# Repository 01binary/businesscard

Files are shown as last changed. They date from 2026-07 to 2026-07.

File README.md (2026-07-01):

# Interactive Business Card

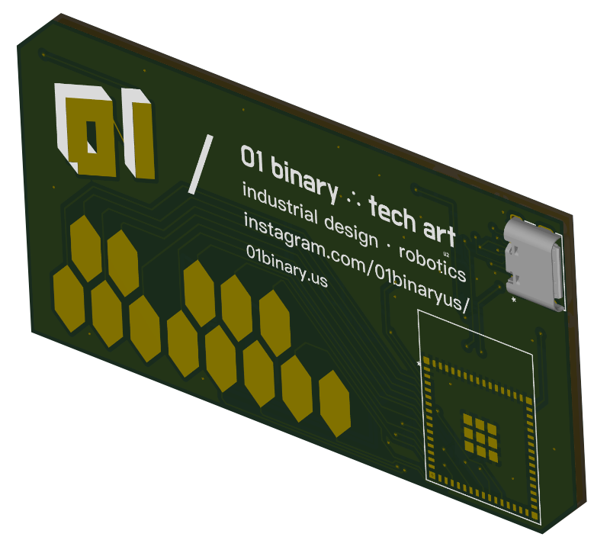
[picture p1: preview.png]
preview


A two-sided PCB business card designed in `KiCad 9`, built around an `ESP32-S2-MINI-2` module, powered by `USB-C` or a `CR2032` coin cell.

+ Capacitive-Touch Piano Keys (`C4`–`C5`, one octave)
+ Piezo Speaker (Monophonic Tone Playback)
+ Capacitive Logo Touch Pad (Wake / Power Control)
+ USB-C or `CR2032` Power, Auto-Switched
+ Deep Sleep for Low Power Consumption

## Modules

The following module is placed onto the board:

|Module|Function|
|-|-|
|`ESP32-S2-MINI-2-N4`|MCU module with native USB, capacitive-touch inputs, and deep sleep|

## Power

Power comes from either a `USB-C` connector (through a `3.3V` LDO regulator) or a `CR2032` coin cell battery.

A `TPS2121` power multiplexer (`U_PWR`) automatically prioritizes `USB` power when plugged in, and switches back to coin cell power when unplugged, with no interruption to the `3.3V` rail.

| Stage | Component | Function |
|-|-|-|
| `USB` → `3.3V` | `AP2112K-3.3` (`U2`) | LDO regulator, converts `VBUS` (`5V`) down to `3.3V` |
| `USB` / Battery Switch | `TPS2121` (`U_PWR`) | Selects `USB 3.3V` or `CR2032 3V`, prioritizing `USB` |
| Coin Cell | Keystone `3034` (`BT1`) | Holder for `20mm CR2032` battery |

Decoupling/bulk capacitors on the `3.3V` rail:

|Capacitor|Value|Purpose|
|-|-|-|
|`C1`|`100µF`|Bulk capacitor, stabilizes rail against low-frequency dips (battery power draw)|
|`C2`|`10µF`|LDO output filter|
|`C3`|`0.1µF`|Local high-frequency bypass near the MCU|

### USB-C Configuration

The `USB-C` receptacle (`J1`) is configured for `UFP` (Upstream Facing Port) mode, meaning the card acts as a `USB` device, not a host.

+ `CC1` and `CC2` are each pulled to `GND` through `5.1kΩ` resistors (`R1`, `R2`), advertising the device role per the `USB Type-C` spec.
+ Only one of `CC1`/`CC2` is active depending on cable orientation, but both are populated so the connector works either way.
+ When plugged in, the host detects the pull-downs and supplies `5V` on `VBUS`.
+ No `USB-PD` negotiation is needed since the board only draws default `5V` at low current.

## Touch Interface

The front of the card has 13 capacitive touch pads forming one octave of piano-style keys (`C4`–`C5`), plus a two-piece logo pad that is electrically bridged into a single touch input.

+ Touching a piano key plays its corresponding tone through the piezo speaker.
+ Touching the logo pad wakes the device from deep sleep and acts as the soft power button.
+ After a period of inactivity, the firmware drops to a reduced CPU frequency and then enters deep sleep; touching the logo is the wake source.
+ All touch pads and I/O are additionally brought out as test points for flexibility in layout and debugging.

## Audio

When a key is touched, the firmware plays a monophonic tone through a piezo transducer (`LS1`), driven differentially from two `GPIO` pins through `100Ω` series resistors (`R3`, `R4`).

## Buttons

|Button|Function|
|-|-|
|`SW1`|`RESET` — pulls `EN` low to reset the MCU|
|`SW2`|`BOOT` — pulls `GPIO0` low to enter flashing mode|

## Pins

|Pin|Function|
|-|-|
|`GPIO19`|USB `D-` (`J1`)|
|`GPIO20`|USB `D+` (`J1`)|
|`GPIO0`|`BOOT` Button (`SW2`)|
|`EN`|`RESET` Button (`SW1`)|
|`3V3`|Power input from `U_PWR` (`TPS2121`) `OUT`|
|`GPIO26`|Piezo Driver `A` → `R3` → `LS1 +`|
|`GPIO17`|Piezo Driver `B` → `R4` → `LS1 -`|
|`GPIO1`|Touch Key `C` (`TP1`)|
|`GPIO2`|Touch Key `C#` (`TP2`)|
|`GPIO3`|Touch Key `D` (`TP3`)|
|`GPIO4`|Touch Key `D#` (`TP4`)|
|`GPIO5`|Touch Key `E` (`TP5`)|
|`GPIO6`|Touch Key `F` (`TP6`)|
|`GPIO7`|Touch Key `F#` (`TP7`)|
|`GPIO8`|Touch Key `G` (`TP8`)|
|`GPIO9`|Touch Key `G#` (`TP9`)|
|`GPIO10`|Touch Key `A` (`TP10`)|
|`GPIO11`|Touch Key `A#` (`TP11`)|
|`GPIO12`|Touch Key `B` (`TP12`)|
|`GPIO13`|Touch Key `C` (octave up) (`TP13`)|
|`GPIO14`|Touch Logo Pad, wake source (`TP14`, bridged)|

## Bill of Materials

|Component|Description|
|-|-|
|[ESP32-S2-MINI-2-N4](https://www.digikey.com/en/products/result?keywords=ESP32-S2-MINI-2-N4)|Main MCU with native USB and capacitive-touch capability|
|[AP2112K-3.3TRG1DICT-ND](https://www.digikey.com/en/products/result?keywords=AP2112K-3.3TRG1)|`3.3V` LDO regulator for USB power source|
|[TPS2121RUXR](https://www.digikey.com/en/products/result?keywords=TPS2121RUXR)|Power multiplexer, auto-switches between USB `3.3V` and `CR2032` battery|
|[Keystone 3034](https://www.digikey.com/en/products/result?keywords=3034)|Holder for `20mm CR2032` battery|
|[UJ20-C-H-G-MSMT-5-P16-TR](https://www.digikey.com/en/products/result?keywords=UJ20-C-H-G-MSMT-5-P16-TR)|USB-C receptacle for power and programming|
|[TLSMDT3C020GLFS](https://www.digikey.com/en/products/detail/c-k/TLSMDT3C020GLFS/14553425)|`SW1`/`SW2` Momentary pushbutton, RESET (`EN`) and BOOT (`GPIO0`)|
|[SMT-1141-T-5-R](https://www.digikey.com/en/products/detail/pui-audio-inc/SMT-1141-T-5-R/6192576)|Piezo transducer, audio output for tone playback|
|[RMCF0603FT5K10CTND](https://www.digikey.com/en/products/result?keywords=RMCF0603FT5K10)|`5.1kΩ` `0603` resistor, USB-C `CC` pull-downs (`R1`, `R2`)|
|[RMCF0603JT100RCTND](https://www.digikey.com/en/products/result?keywords=RMCF0603JT100R)|`100Ω` `0603` resistor, piezo driver series protection (`R3`, `R4`)|
|[CL32A107MPVNNNE](https://www.digikey.com/en/products/result?keywords=CL32A107MPVNNNE)|`100µF` capacitor, bulk power stabilization (`C1`)|
|[GRM21BR61C106KE15K](https://www.digikey.com/en/products/result?keywords=GRM21BR61C106KE15K)|`10µF` `0805` capacitor, LDO output filter (`C2`)|
|[CS0805KKX7R0BB104](https://www.digikey.com/en/products/result?keywords=CS0805KKX7R0BB104)|`0.1µF` `0603` capacitor, local bypass near MCU (`C3`)|

`TP1`–`TP13` are capacitive piano key electrodes (`C4`–`C5`); `TP14` is the two-piece logo pad bridged into a single wake-source input. Neither requires a physical component.

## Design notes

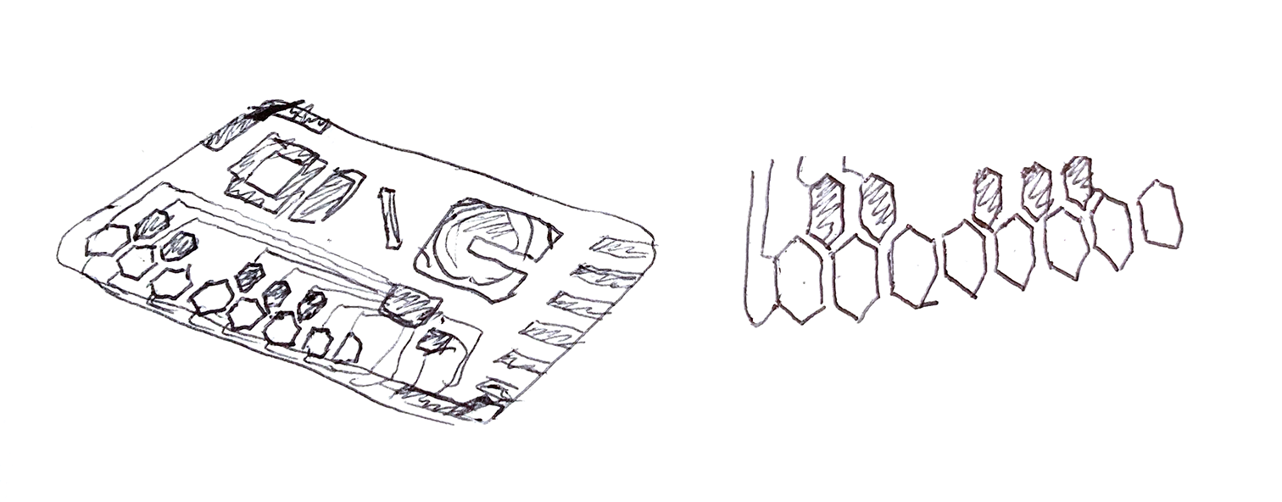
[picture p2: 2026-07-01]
design/concept.png

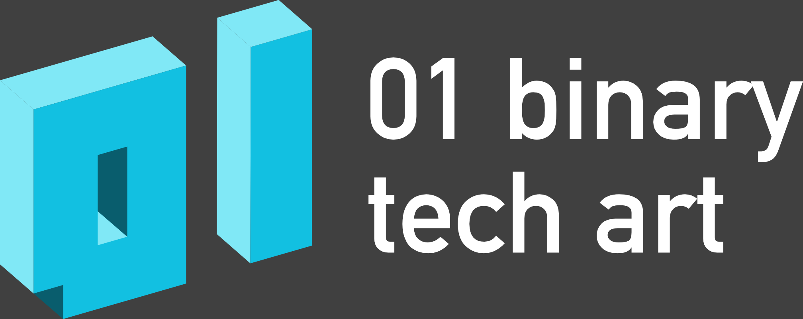
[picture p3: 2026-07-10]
design/01text.png

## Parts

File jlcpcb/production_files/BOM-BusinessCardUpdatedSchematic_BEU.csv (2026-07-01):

Comment | Designator | Footprint | LCSC | Quantity
0.1uF | C3,C6,C9 | CL10B104KA8NNNC | C1590 | 3
100 | R3,R4 | RESC1508X55N | C305084 | 2
100K | R5 | RC0805FR-07100KL | C96346 | 1
100uF | C1 | CAPC3225X280N | C23742 | 1
10K | R7,R8 | AF0805FR-0710KL | C192906 | 2
10uF | C2,C7 | CL10A106KP8NNNC | C19702 | 2
1uF | C4,C5 | GRM188R71A105KA61D | C97888 | 2
2171790001 | J1 | 2171790001_MOL | C45082768 | 1
3034 | BT1 | BAT_3034 | C5213768 | 1
5.1K | R1,R2 | RC0603FR-075K1L | C105580 | 2
AP2112K-3.3TRG1 | U2 | SOT95P285X140-5N | C51118 | 1
ESP32-S3-MINI-1-N8 | U3 | ESP32-S3-MINI-1-N8 | C2913206 | 1
TLSMDT3C020GLFS | SW2,SW3 | TS-1088-AR02016 | C720477 | 2
TPS2121RUXR | U_PWR1 | IC_TPS2121RUXR | C485916 | 1

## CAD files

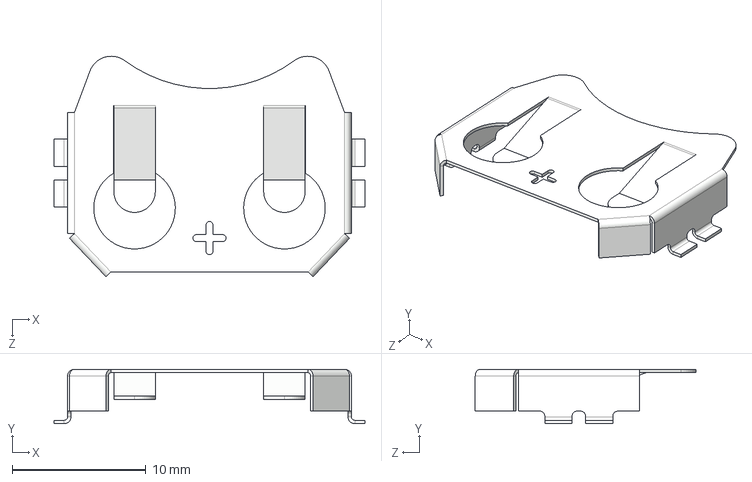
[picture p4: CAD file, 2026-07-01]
dependencies/6-3034-ND/3034.step
23.2 x 4.06 x 16.5 mm

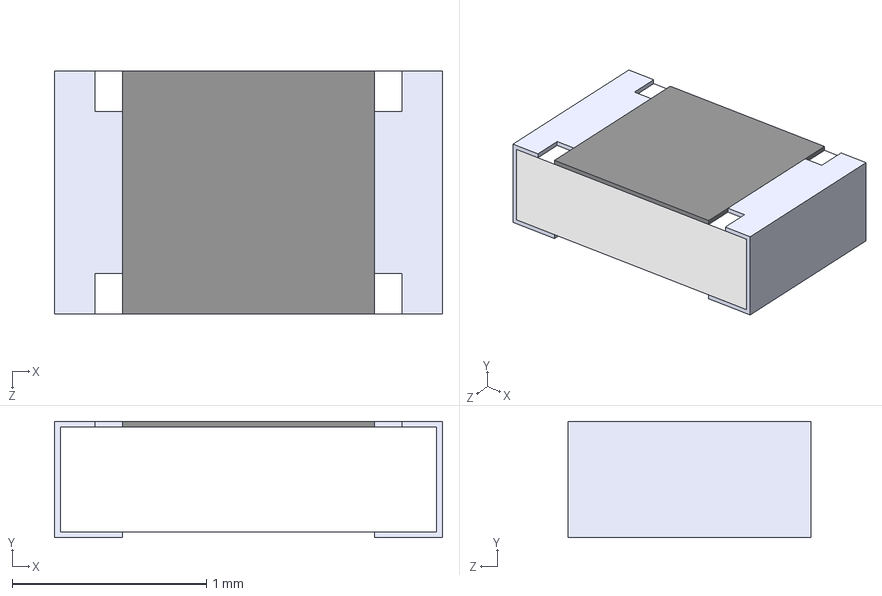
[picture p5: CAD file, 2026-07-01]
dependencies/AF0805FR-0710KL/AF0805FR-0710KL.step
2.00 x 0.6 x 1.25 mm

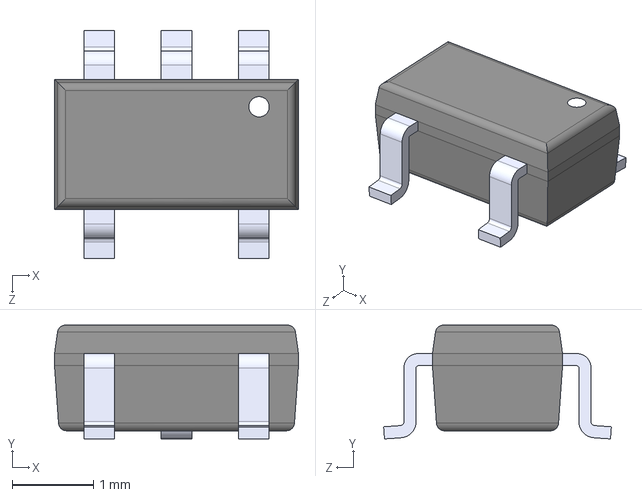
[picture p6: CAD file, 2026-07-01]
dependencies/AP2112K-3.3TRG1/AP2112K-3.3TRG1.step
3.00 x 1.40 x 2.80 mm

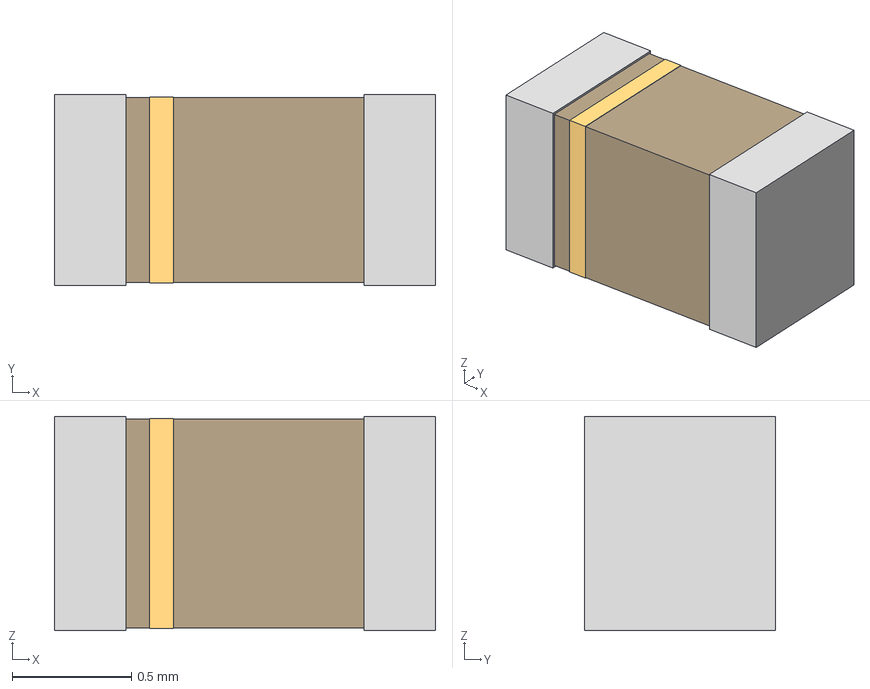
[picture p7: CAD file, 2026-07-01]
dependencies/CL10A106KP8NNNC/CL10A106KP8NNNC.step
1.60 x 0.8 x 0.9 mm

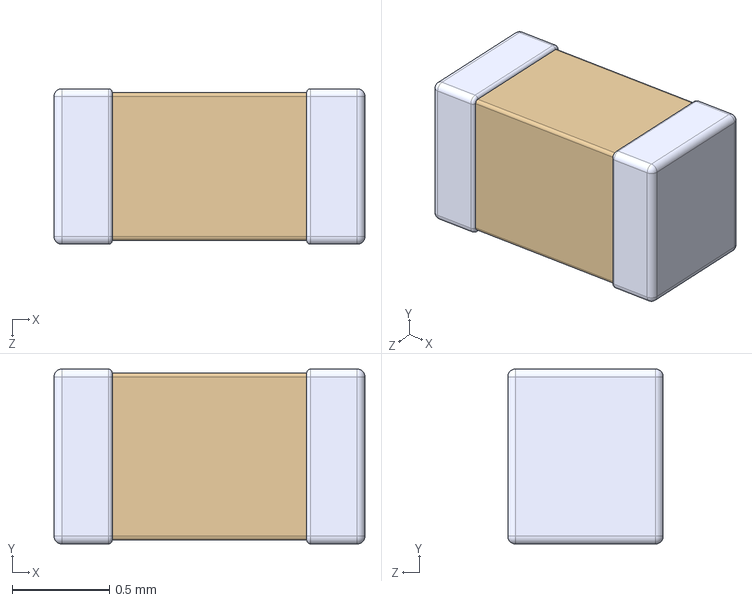
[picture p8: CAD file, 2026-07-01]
dependencies/CL10B104KA8NNNC/CL10B104KA8NNNC.step
1.60 x 0.9 x 0.8 mm

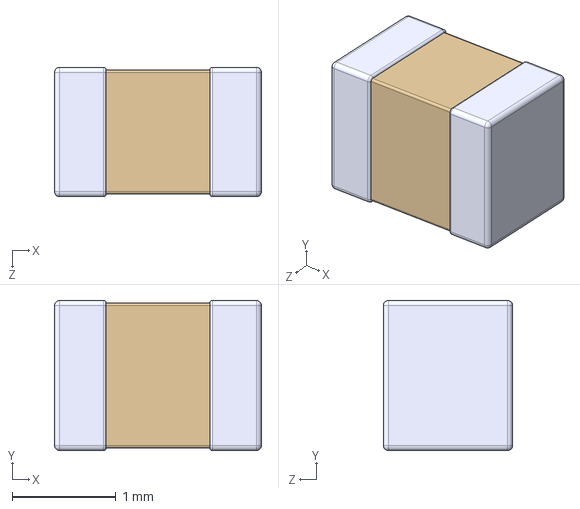
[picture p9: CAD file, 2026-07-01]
dependencies/CL21A106KAYNNNF/CL21A106KAYNNNF.step
2.00 x 1.45 x 1.25 mm

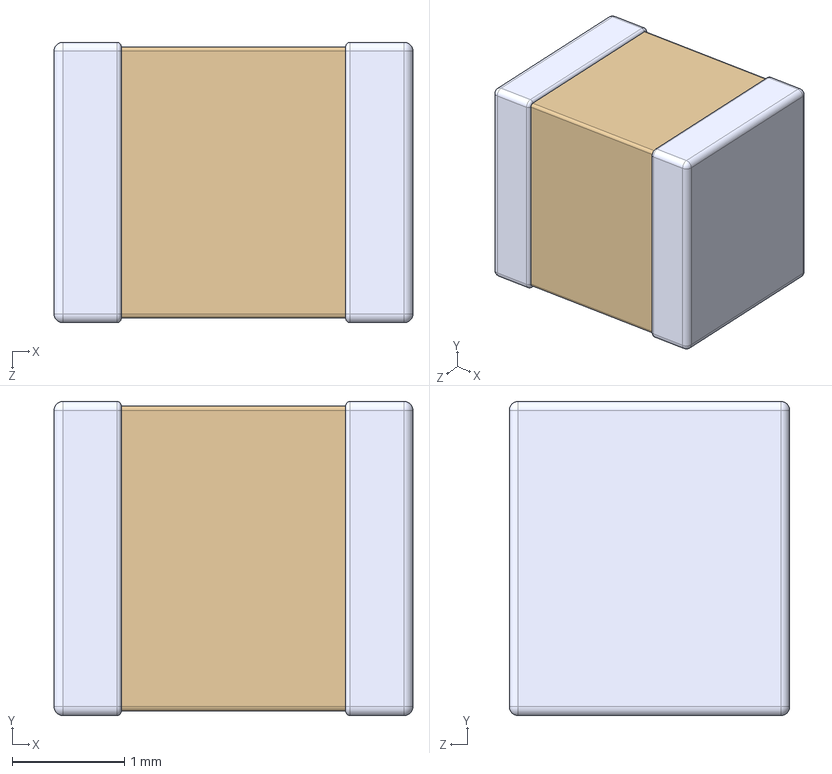
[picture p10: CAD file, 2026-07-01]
dependencies/CL32A107MPVNNNE/CL32A107MPVNNNE.step
3.20 x 2.80 x 2.50 mm

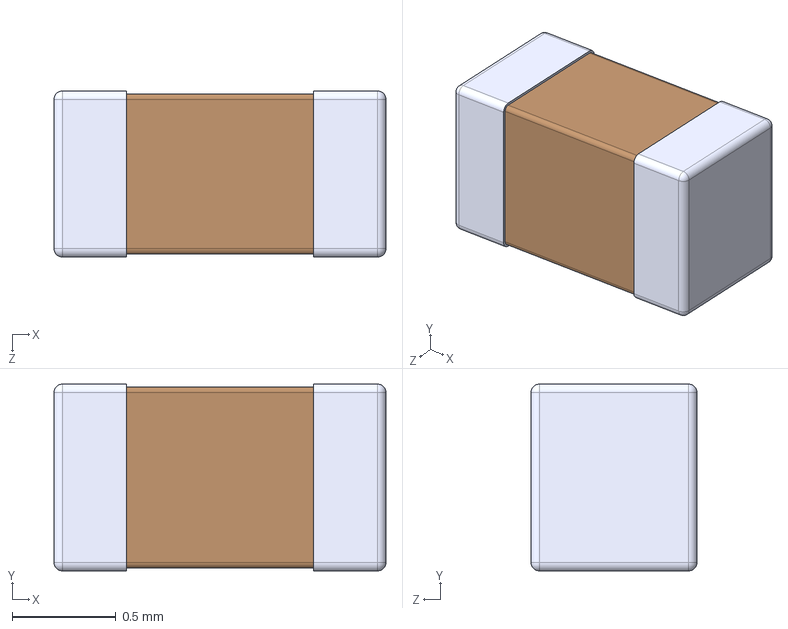
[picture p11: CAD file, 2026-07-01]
dependencies/GRM188R71A105KA61D/GRM188R71A105KA61D.step
1.60 x 0.9 x 0.8 mm

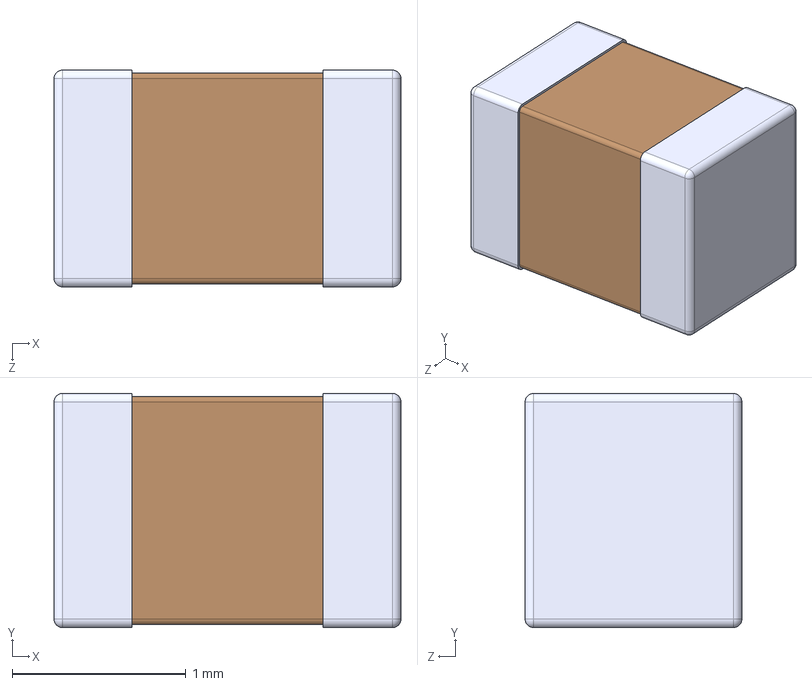
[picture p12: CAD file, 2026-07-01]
dependencies/GRM21BR61C106KE15K/GRM21BR61C106KE15K.step
2.00 x 1.35 x 1.25 mm

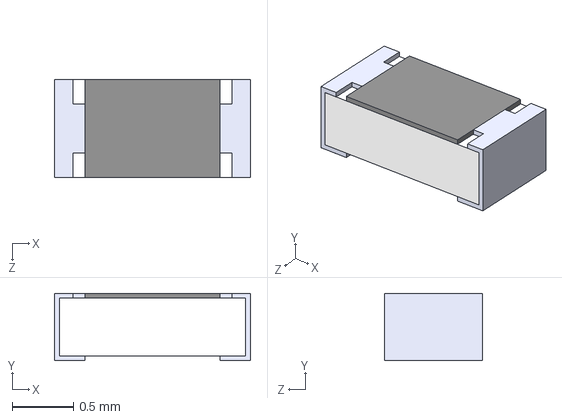
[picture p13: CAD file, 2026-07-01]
dependencies/RC0603FR-075K1L/RC0603FR-075K1L.step
1.60 x 0.55 x 0.8 mm

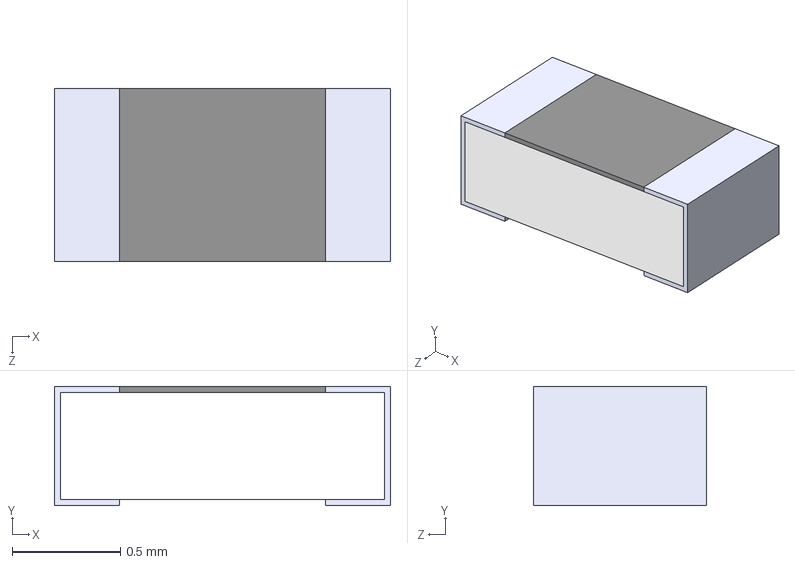
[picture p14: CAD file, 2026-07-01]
dependencies/RMCF0603FT5K10/RMCF0603FT5K10.step
1.55 x 0.55 x 0.8 mm

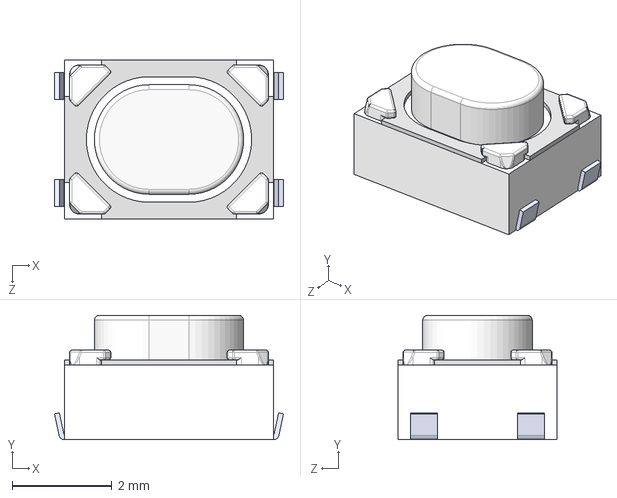
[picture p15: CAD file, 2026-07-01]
dependencies/SKRPABE010/SKRPABE010.step
4.60 x 2.50 x 3.20 mm

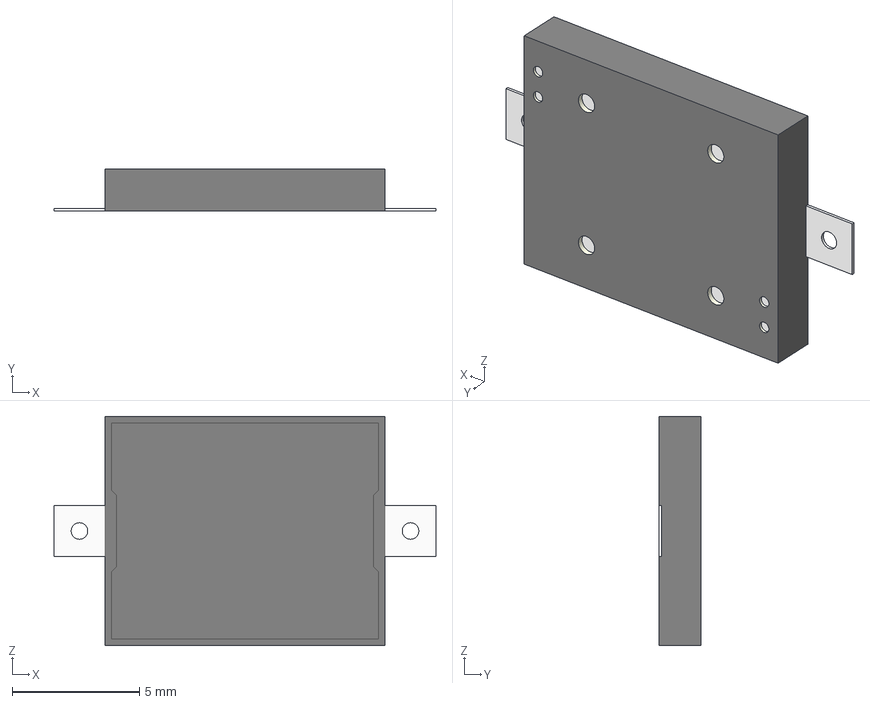
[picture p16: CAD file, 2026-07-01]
dependencies/SMT_1141_T_5_R/SMT-1141-T-5-R.step
15.0 x 1.65 x 9.00 mm

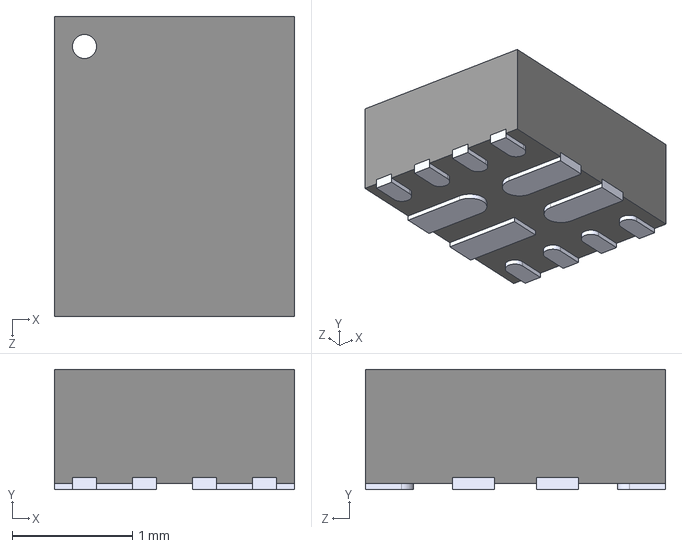
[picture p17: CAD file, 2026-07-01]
dependencies/TPS2121RUXR/TPS2121RUXR.step
2.00 x 1.00 x 2.50 mm

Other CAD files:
dependencies/CC0805KKX5R5BB106/CC0805KKX5R5BB106.step
dependencies/TS-1088-AR02016/TS-1088-AR02016.step
dependencies/2171790001/2171790001.stp
dependencies/UJ20_C_H_G_MSMT_5_P16_TR/UJ20-C-H-G-MSMT-5-P16-TR.step
resources/front.dwg
resources/logo.dwg

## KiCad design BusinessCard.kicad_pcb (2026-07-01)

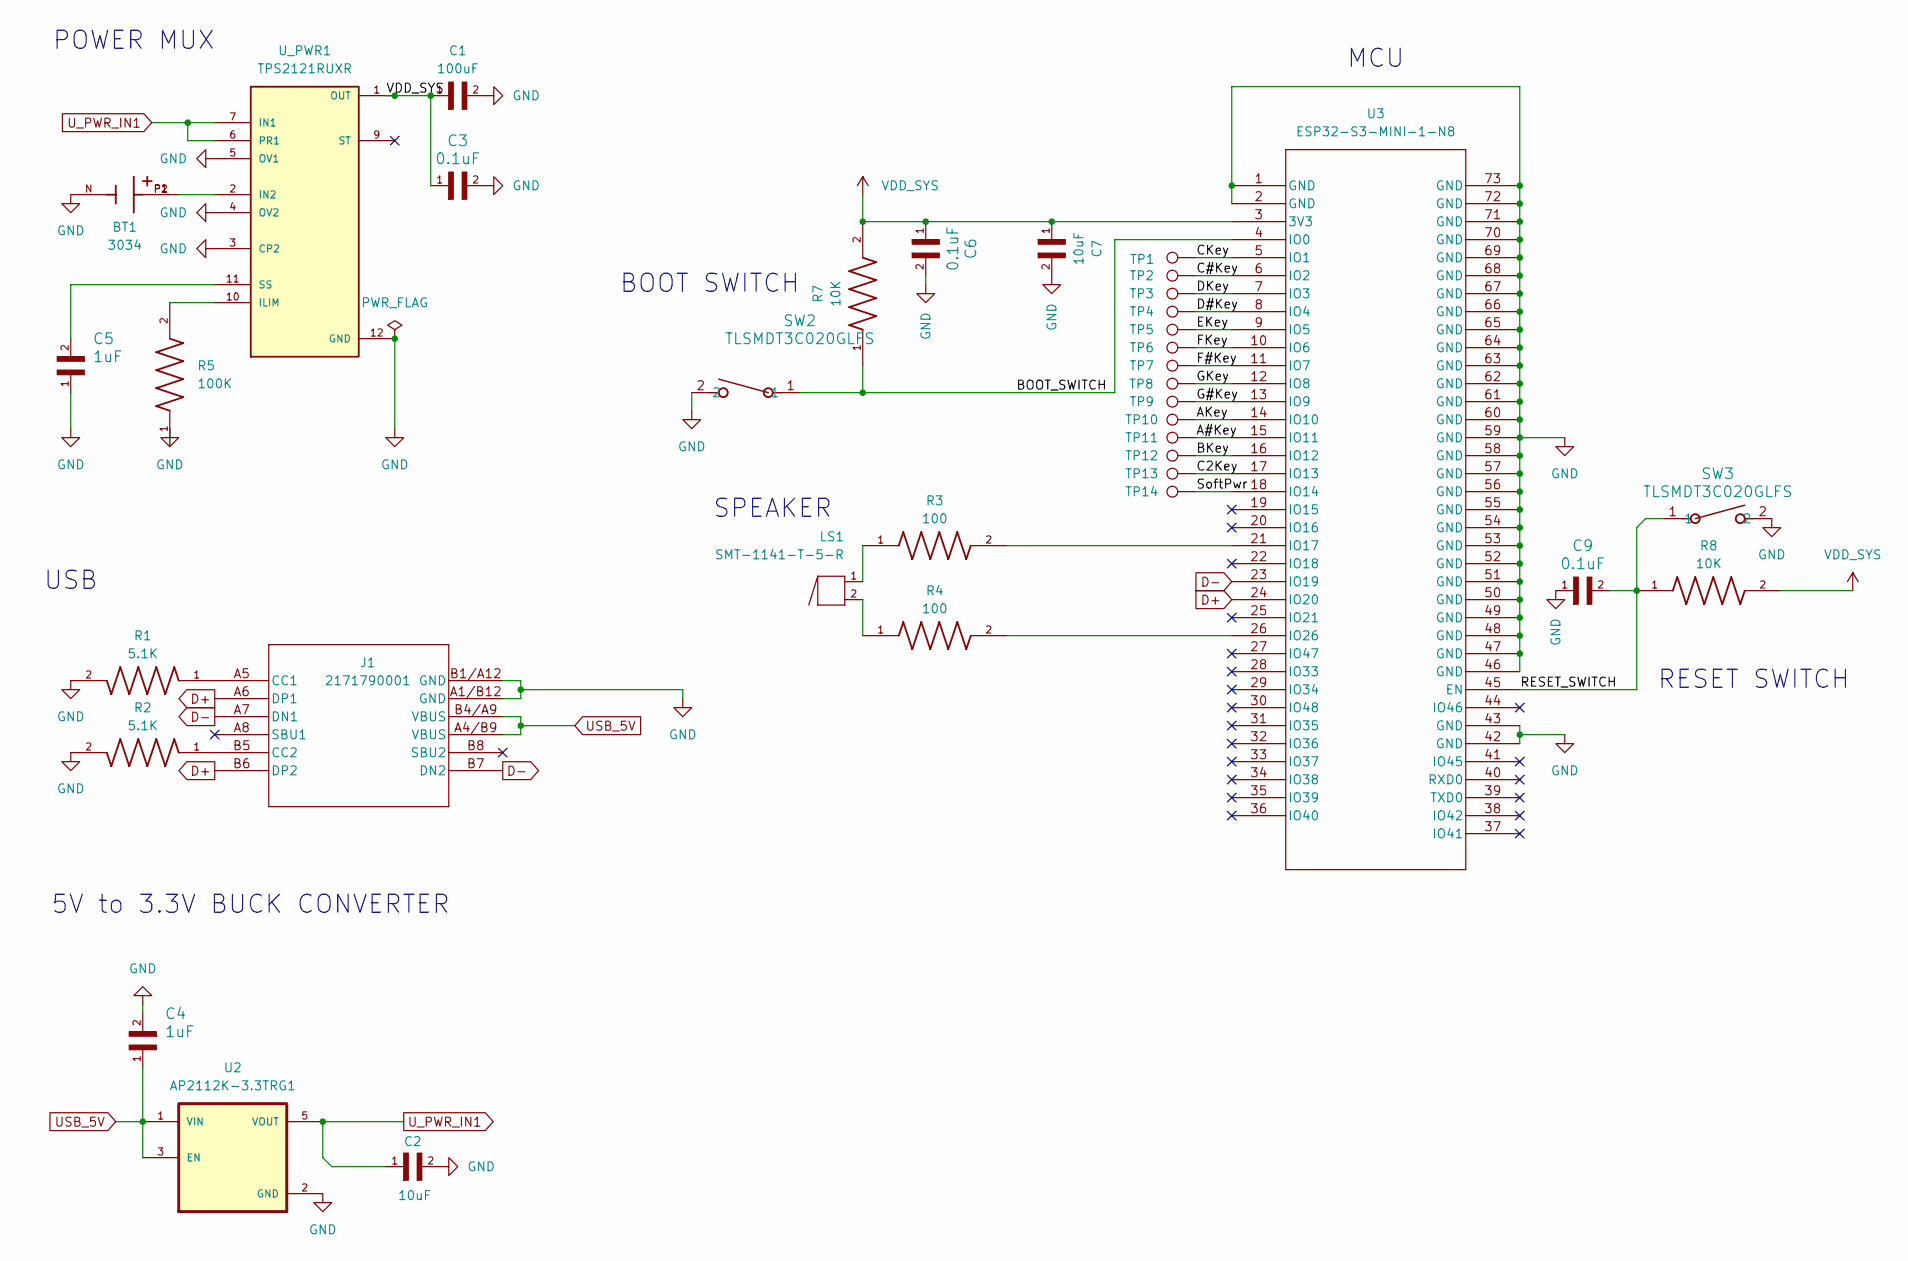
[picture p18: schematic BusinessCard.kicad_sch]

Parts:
BT1: 3034; BAT_3034; PARTREV E; DigiKey_Part_Number 36-3034-ND
C1: 100uF; CAPC3225X280N; LCSC C23742
C2: 10uF; CL10A106KP8NNNC; LCSC C19702
C3, C6, C9: 0.1uF; CL10B104KA8NNNC; DigiKey_Part_Number 1276-1006-1-ND
C4, C5: 1uF; GRM188R71A105KA61D; LCSC C97888
C7: 10uF; CL10A106KP8NNNC; DigiKey_Part_Number 1276-CL21A106KAYNNNFTR-ND
J1: 2171790001; 2171790001_MOL; PARTREV 1.0; LCSC C45082768
LS1: SMT-1141-T-5-R; XDCR_SMT-1141-T-5-R; PARTREV A; LCSC C6680782
R1, R2: 5.1K; RC0603FR-075K1L; LCSC C105580
R3, R4: 100; RESC1508X55N; LCSC C305084
R5: 100K; RC0805FR-07100KL; DigiKey_Part_Number 311-100KCRCT-ND
R7, R8: 10K; AF0805FR-0710KL; DigiKey_Part_Number 13-AF0805FR-0710KLCT-ND
SW2, SW3: TLSMDT3C020GLFS; TS-1088-AR02016; LCSC C720477
TP1, TP2, TP3, TP4, TP5, TP6, TP7, TP8, TP9, TP10, TP11, TP12, TP13: TestPoint; BusinessCardPad
TP14: TestPoint; BusinessCardLogo
U2: AP2112K-3.3TRG1; SOT95P285X140-5N; PARTREV 2-2; LCSC C51118
U3: ESP32-S3-MINI-1-N8; PARTREV v0.5; LCSC C2913206
U_PWR1: TPS2121RUXR; IC_TPS2121RUXR; LCSC C485916

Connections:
/A#Key: TP11.1, U3.15 (IO11)
/AKey: TP10.1, U3.14 (IO10)
/BKey: TP12.1, U3.16 (IO12)
/BOOT_SWITCH: R7.1, SW2.1, U3.4 (IO0)
/C2Key: TP13.1, U3.17 (IO13)
/C#Key: TP2.1, U3.6 (IO2)
/CKey: TP1.1, U3.5 (IO1)
/D#Key: TP4.1, U3.8 (IO4)
/DKey: TP3.1, U3.7 (IO3)
/EKey: TP5.1, U3.9 (IO5)
/F#Key: TP7.1, U3.11 (IO7)
/FKey: TP6.1, U3.10 (IO6)
/G#Key: TP9.1, U3.13 (IO9)
/GKey: TP8.1, U3.12 (IO8)
/RESET_SWITCH: C9.2, R8.1, SW3.1, U3.45 (EN)
/SoftPwr: TP14.1, U3.18 (IO14)
D+: J1.A6 (DP1), J1.B6 (DP2), U3.24 (IO20)
D-: J1.A7 (DN1), J1.B7 (DN2), U3.23 (IO19)
GND: BT1.N, C1.2, C2.2, C3.2, C4.2, C5.1, C6.2, C7.2, C9.1, J1.A1/B12 (GND), J1.B1/A12 (GND), R1.2, R2.2, R5.1, SW2.2, SW3.2, U2.2 (GND), U3.1 (GND), U3.2 (GND), U3.42 (GND), U3.43 (GND), U3.46 (GND), U3.47 (GND), U3.48 (GND), U3.49 (GND), U3.50 (GND), U3.51 (GND), U3.52 (GND), U3.53 (GND), U3.54 (GND), U3.55 (GND), U3.56 (GND), U3.57 (GND), U3.58 (GND), U3.59 (GND), U3.60 (GND), U3.61 (GND), U3.62 (GND), U3.63 (GND), U3.64 (GND), U3.65 (GND), U3.66 (GND), U3.67 (GND), U3.68 (GND), U3.69 (GND), U3.70 (GND), U3.71 (GND), U3.72 (GND), U3.73 (GND), U_PWR1.3 (CP2), U_PWR1.4 (OV2), U_PWR1.5 (OV1), U_PWR1.12 (GND)
unnamed: J1.A5 (CC1), R1.1
unnamed: J1.B5 (CC2), R2.1
unnamed: LS1.1, R3.1
unnamed: LS1.2, R4.1
unnamed: R3.2, U3.21 (IO17)
unnamed: R4.2, U3.26 (IO26)
unnamed: R5.2, U_PWR1.10 (ILIM)
unnamed: BT1.P1, BT1.P2, U_PWR1.2 (IN2)
unnamed: C5.2, U_PWR1.11 (SS)
USB_5V: C4.1, J1.A4/B9 (VBUS), J1.B4/A9 (VBUS), U2.1 (VIN), U2.3 (EN)
U_PWR_IN1: C2.1, U2.5 (VOUT), U_PWR1.6 (PR1), U_PWR1.7 (IN1)
VDD_SYS: C1.1, C3.1, C6.1, C7.1, R7.2, R8.2, U3.3 (3V3), U_PWR1.1 (OUT)

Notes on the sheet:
MCU
USB
POWER MUX
SPEAKER
RESET SWITCH
5V to 3.3V BUCK CONVERTER
BOOT SWITCH

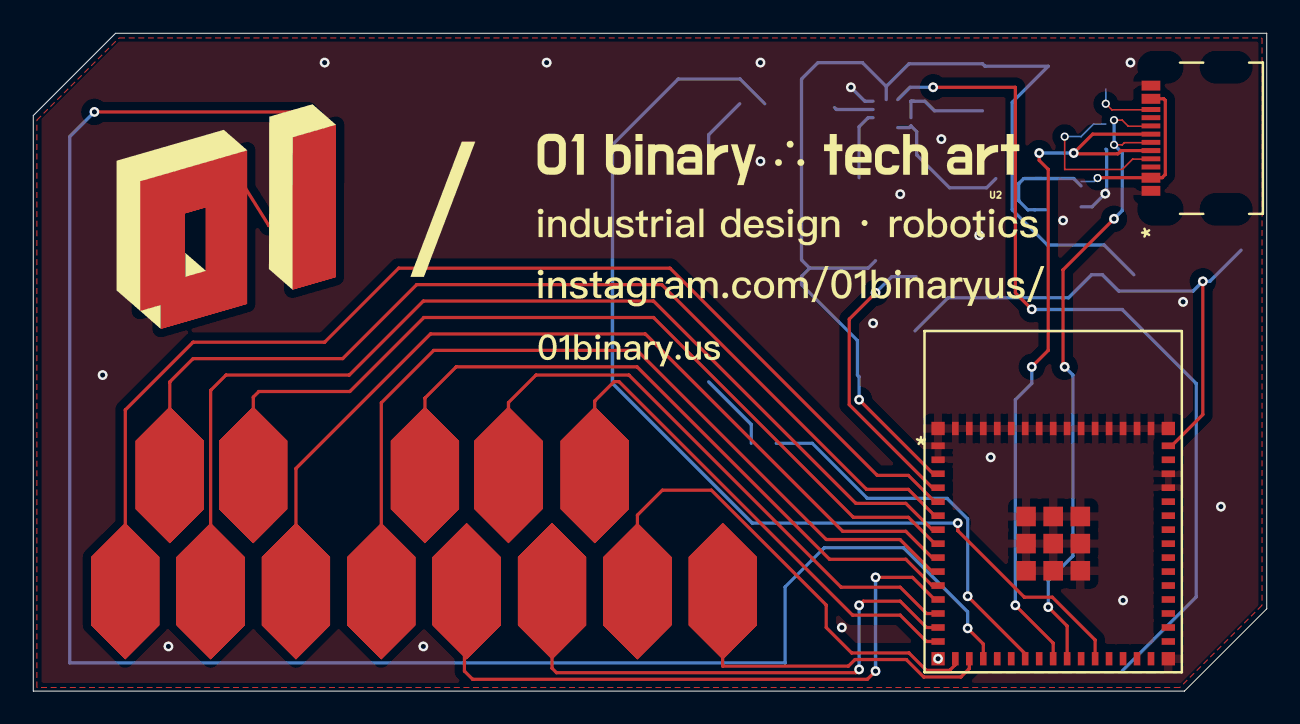
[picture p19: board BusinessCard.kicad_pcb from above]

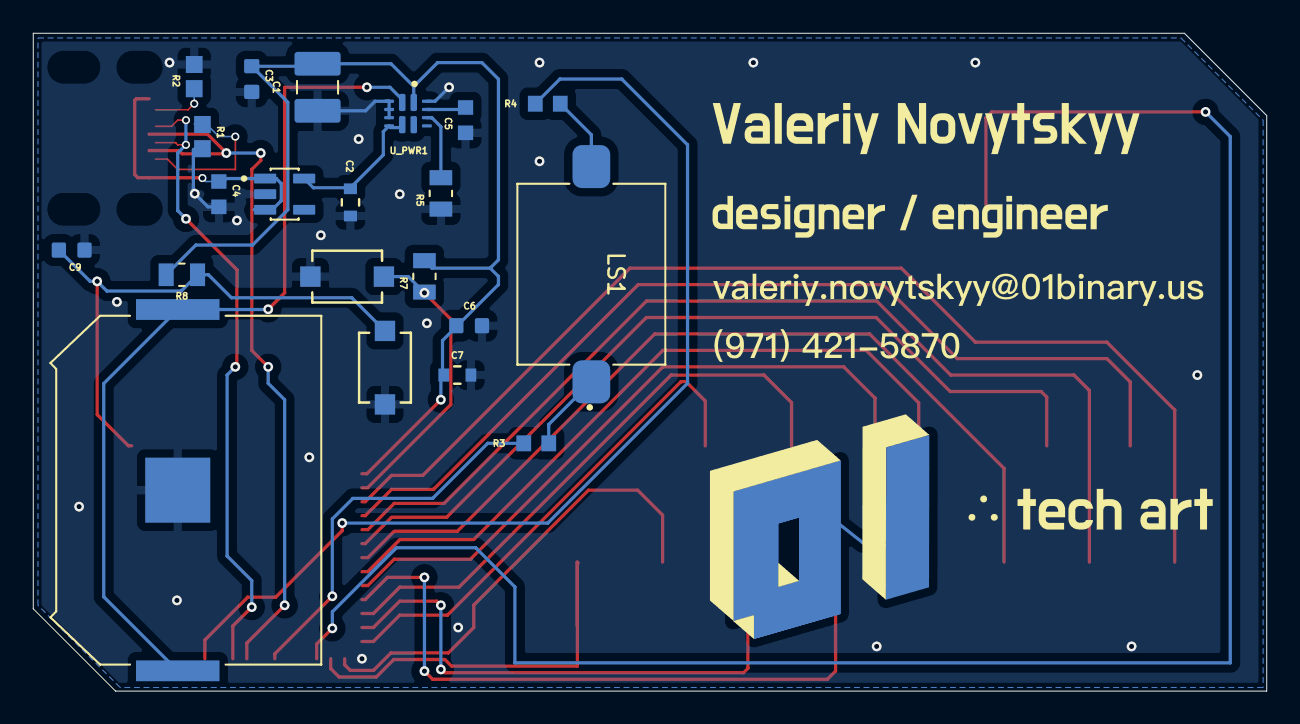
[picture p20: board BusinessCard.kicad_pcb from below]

Board: 2 copper layers, 75.0 x 40.0 mm, 37 parts (21 on the bottom side), 31 nets.

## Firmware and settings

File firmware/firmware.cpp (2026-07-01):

#include <Arduino.h>
#include "driver/touch_pad.h"
#include "driver/ledc.h"

// =======================
// Configuration Constants
// =======================
constexpr int TOUCH_LOGO_PIN = 14;
constexpr int PIEZO_PIN_A = 26;
constexpr int PIEZO_PIN_B = 17;
constexpr int CPU_FREQ_MHZ = 80;          // Lower frequency to save power
constexpr uint32_t SLEEP_TIMEOUT_MS = 15000;
constexpr uint32_t DEBOUNCE_DELAY_MS = 50;

// Piano keys (C4 to C5)
constexpr int TOUCH_KEYS[] = {1, 2, 3, 4, 5, 6, 7, 8, 9, 10, 11, 12, 13};
constexpr float PIANO_FREQS[] = {
  261.63, 277.18, 293.66, 311.13, 329.63, 349.23, 369.99,
  392.00, 415.30, 440.00, 466.16, 493.88, 523.25
};

constexpr int NUM_KEYS = sizeof(TOUCH_KEYS) / sizeof(TOUCH_KEYS[0]);

// =======================
// State Variables
// =======================
uint32_t lastTouchTime = 0;
int currentKey = -1;

// =======================
// Utility Functions
// =======================
void playTone(float freq) {
  if (freq <= 0) {
    ledcWriteTone(0, 0);
    return;
  }
  ledcWriteTone(0, freq);
}

int getActiveKey() {
  int activeKeys[NUM_KEYS];
  int activeCount = 0;

  for (int i = 0; i < NUM_KEYS; i++) {
    if (touchRead(TOUCH_KEYS[i]) < 40) { // Threshold, may need tuning
      activeKeys[activeCount++] = i;
    }
  }

  if (activeCount == 0) return -1;

  // Choose center key if multiple touched
  int centerIdx = activeCount / 2;
  return activeKeys[centerIdx];
}

void goToDeepSleep() {
  playTone(0);
  touchSleepWakeUpEnable((touch_pad_t)TOUCH_LOGO_PIN, 40);
  esp_deep_sleep_start();
}

// =======================
// Setup
// =======================
void setup() {
  // Lower CPU frequency
  setCpuFrequencyMhz(CPU_FREQ_MHZ);

  Serial.begin(115200);

  // Touch init
  touch_pad_init();
  for (int i = 0; i < NUM_KEYS; i++) {
    touchAttachInterrupt(TOUCH_KEYS[i], nullptr, 40);
  }
  touchAttachInterrupt(TOUCH_LOGO_PIN, nullptr, 40);

  // Piezo output (using PWM on one pin)
  ledcSetup(0, 2000, 10);
  ledcAttachPin(PIEZO_PIN_A, 0);

  lastTouchTime = millis();
}

// =======================
// Main Loop
// =======================
void loop() {
  int newKey = getActiveKey();

  if (newKey != -1 && newKey != currentKey) {
    delay(DEBOUNCE_DELAY_MS);
    if (getActiveKey() == newKey) {
      playTone(PIANO_FREQS[newKey]);
      currentKey = newKey;
      lastTouchTime = millis();
    }
  } else if (newKey == -1 && currentKey != -1) {
    playTone(0);
    currentKey = -1;
  }

  if (millis() - lastTouchTime > SLEEP_TIMEOUT_MS) {
    goToDeepSleep();
  }
}
